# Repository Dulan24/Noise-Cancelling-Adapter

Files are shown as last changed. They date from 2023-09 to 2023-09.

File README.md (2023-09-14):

# Noise Cancelling Adapter

This project was targeting a cost-reduced noise-cancelling adapter which will cancel the ambient noise 
up to a certain level. Any headphone can be connected to the adapter and the adapter should be 
connected to the audio port of the device we are using. Then we have to switch on the adapter so that 
we can hear the music with noise reduced.  

Existing noise-cancelling headphones in the market are quite expensive. If a person has a normal 
headphone and he wants a noise-cancelling headphone, that person has to buy a separate 
headphone to it. It is a waste of money. Considering all these factors, I decided to design a noise-cancelling adapter to convert a normal headphone to a noise cancelling headphone. Since this is only 
an adapter it will be able to make this at lower cost. 

final product

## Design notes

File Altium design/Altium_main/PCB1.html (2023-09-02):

Altium customize

# Board Information Report

Date: | | 23-Jul-23
Time: | | 8:04:15 AM
Elapsed Time: | | 00:00:00
Filename: | | C:\Users\Dulan Lokugeegana\Desktop\Dulan_Mora\Acadamics\sem4\EN2160_electronic_design_realization\project\PCB\Altium_main\PCB1.PcbDoc
Units: | | mmmils

## Contents

Contents

Board Specification

General

## Board Specification

General
Board Size | 57mm x 66mm
Components on board | 36

Back to top

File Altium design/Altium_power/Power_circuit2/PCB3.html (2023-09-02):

Altium customize

# Board Information Report

Date: | | 23-Jul-23
Time: | | 8:03:48 AM
Elapsed Time: | | 00:00:00
Filename: | | C:\Users\Dulan Lokugeegana\Desktop\Dulan_Mora\Acadamics\sem4\EN2160_electronic_design_realization\project\PCB\Altium_power\Power_circuit2\PCB3.PcbDoc
Units: | | mmmils

## Contents

Contents

Board Specification

General

## Board Specification

General
Board Size | 57mm x 43mm
Components on board | 20

Back to top

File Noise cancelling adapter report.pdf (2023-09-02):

1 | P a g e

# University of Moratuwa

# Department of Electronics and Telecommunication

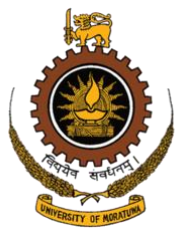
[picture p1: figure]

### EN2160 – Engineering Design Realization

### Report

### Noise Cancelling Adapter

200356A

2 | P a g e

## Table of Contents

3 | P a g e

4 | P a g e

List of figures

5 | P a g e

6 | P a g e

Acknowledgement

This report on Analog Noise Cancelling Adapter project, completed under the electronic part, is being submitted in great pleasure. In order to better grasp this section before learning any theories, we would like to express our profound gratitude to the following people.

My deepest gratitude is conveyed to the head of the department of Electronic and Telecommunication Dr. Ranga Rodrigo and all the senior and junior lecturers who guide us to do such a project. Specially, Dr. Jayathu who gave his views and more ideas in the mid evaluation and helped us in various ways to complete this project.

I would also want to express our gratitude to Prof. J.A.K.S. Jayasinghe for your valuable lectures that helped me accomplish this project in the manner of professional engineers. Analysis, production planning, final product packaging, design strategy, and other topics were all covered in our training. This gave us some insight into how to create the finished product.

Moreover, I convey my gratitude to all my batch mates who helped me immensely by working together and buying components together.

Dulan Lokugeegana,

Electronic and Telecommunication department,

University of Moratuwa,

Sri Lanka.

7 | P a g e

Abstract

The goal of this project is to buy a product which is readily available in the market and add a new feature which is not existing in that product. I decided to buy a normal headphone and add the new feature noise cancelling to it. The main marketing strategy is the cost saving. Normal headphone noise cancelling headphones are so much expensive. The cost of a normal headphone and the noise cancelling adapter is much less than the cost of noise cancelling headphone. In the first hand I thought of having the noise capturing microphones to be inside the adapter but, I found out that it should be near the ear. So, I had to add the mics with cables which should be attached to the headphone. All the calculations, component selection, PCB design and encloser design was done in such a way that the product is marketable.

8 | P a g e

Chapter 1 – Introduction

This project was targeting a cost reduced noise cancelling adapter which will cancel the ambient noise up to a certain level. Any headphone can be connected to the adapter and the adapter should be connected to the audio port of the device we are using. Then we have to switch on the adapter so that we can hear the music with noise reduced.

Problem identification

Existing noise cancelling headphones in the market are quite expensive. If a person has a normal headphone and he wants a noise cancelling headphone, that person has to buy an separate headphone to it. It is a waste of money. Considering all these things, it was decided to design a noise cancelling adapter to convert a normal headphone to a noise cancelling headphone. Since this is only an adapter it will be able to make this at lower cost.

Project objectives

Making a noise cancelling adapter at a lower cost. Moreover, there are other factors that should be consider like weight, size, shape, etc.… Most of the market available adapters are only able to be connected to laptops. Therefore, the product objectives are making a noise cancelling adapter which can be connected to any device, and it should be made at a lower cost with reduced size.

9 | P a g e

Project

The main concept used is capture the noise signal invert it and sum it with the music. Initially noise capturing mics was kept inside the adapter. Then a single mic can capture the noise. Music for the left and the right ears are separately inverted using unity gain inverting amplifier. Next music is added to noise by using a summing amplifier. Finally output the noiseless music for a 3.5mm jack.

First problem occurred is noise capturing. To capture the noise heard to ears the mic should be kept near the ear not in the adapter. Therefore, device needed 2 separate mics to capture the noise and they should be extending outwards. Two separate enclosers were made to insert mic modules which are needed to be connected to the headphone. Both mics are connected from two separate wires.

The second problem is power. Power to make the adapter working cannot be taking from a USB port as this should support any device (which might not have USB port). Therefore, separate replaceable 9V battry was used. Using buck convertor 9V is divided for +4.5V and -4.5V to power up the op amps which is used for amplifiers.

Since electrical signals are travelling at speed of light and sound is much slower comparatively. There should be a delay for negative noise before adding with the music. Therefore, an All Pass Filter is used to compensate it.

Delay calculation

Figure 1 delay calculation

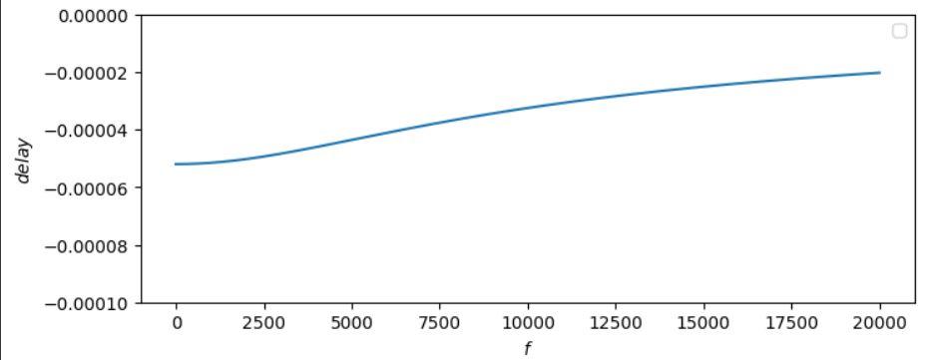
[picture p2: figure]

10 | P a g e

Figure 2 delay curve

Negative phase shift indicates movement to the right.

The mic is kept at about 1.4cm away from the ear.

Figure 3 distance time delay calculation

11 | P a g e

Block diagram

Figure 4 Basic Block Diagram

Basic Circuit Diagram

Figure 5 Basic Circuit Diagram

The above circuit modified and review from [1]

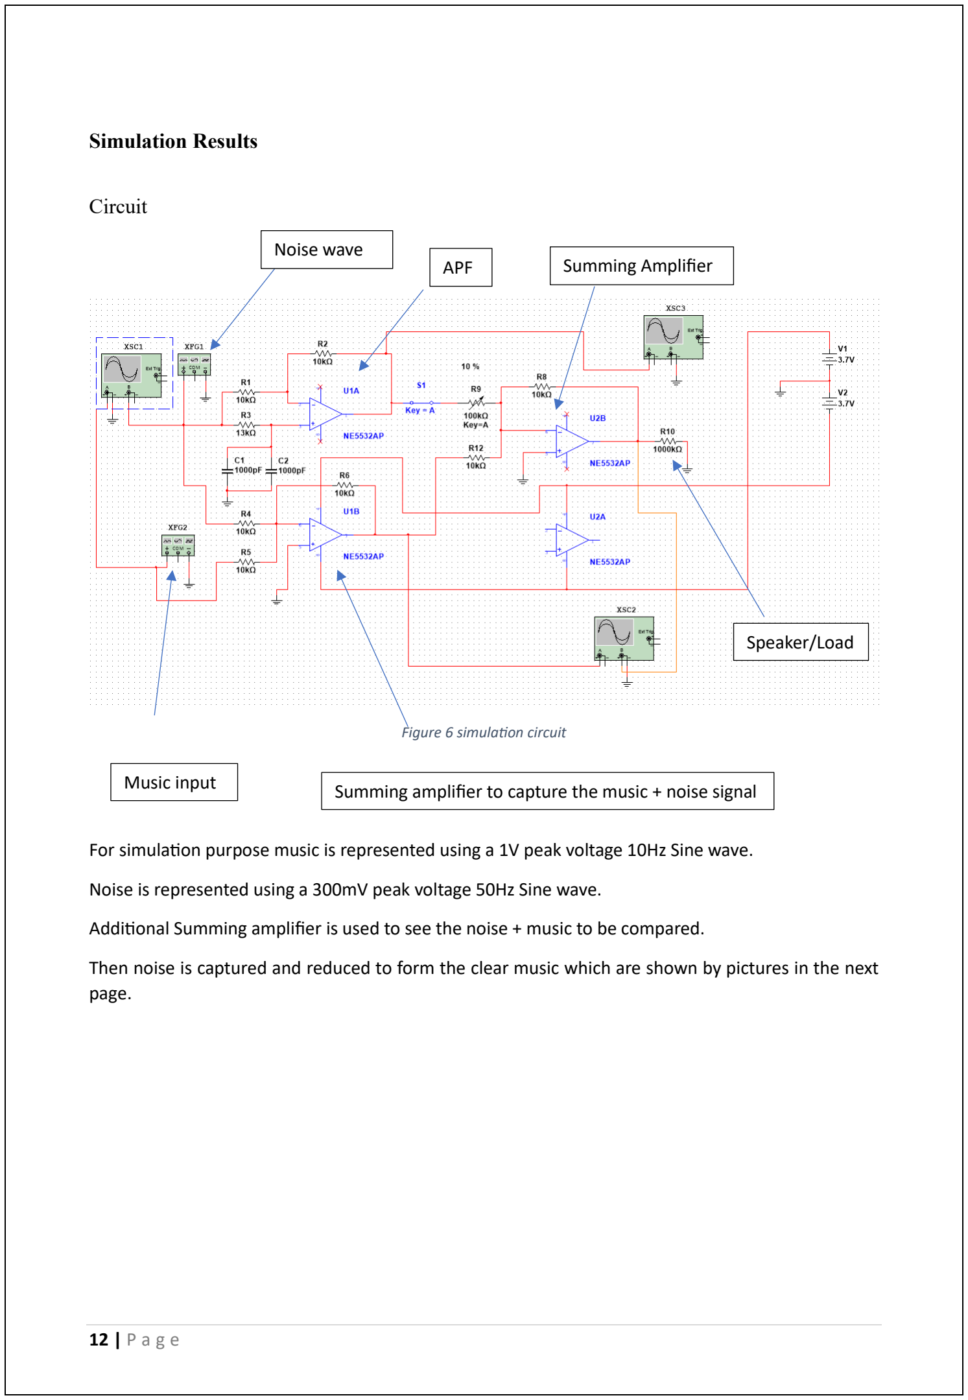
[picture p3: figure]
Simulation Results; Circuit; Figure 6 simulation circuit; page.; Noise wave; Music input; APF; Summing Amplifier; Speaker/Load

For simulation purpose music is represented using a 1V peak voltage 10Hz Sine wave.

Noise is represented using a 300mV peak voltage 50Hz Sine wave.

Additional Summing amplifier is used to see the noise + music to be compared.

Then noise is captured and reduced to form the clear music which are shown by pictures in the next

Summing amplifier to capture the music + noise signal

13 | P a g e

Figure 7 simulation result 1

Figure 8 simulation result 2

Noise signal | Music

Music with noise

Music noise free

14 | P a g e

Chapter 2 – conceptual report

Conceptual design was done with the group members to get more ideas and their opinion on designing the product.

Sketches Drawn by Group Members

Sketch 1
Drawn by Amarasinghe Y.E - 200029B

Figure 10 sketch 1

Figure 9 3D view 1

15 | P a g e

Sketch 2
Drawn by Vishagar A - 200686J

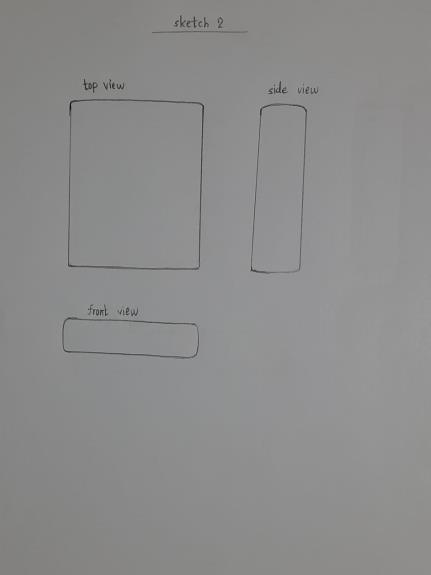
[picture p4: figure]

Figure 11 sketch 2

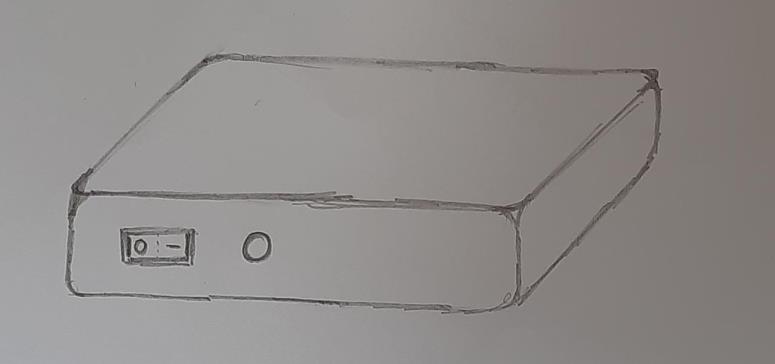
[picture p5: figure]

Figure 12 3D view 2

16 | P a g e

Sketch 3
Drawn by Liyanage P.H.S. – 200352H

Figure 13 sketch 3

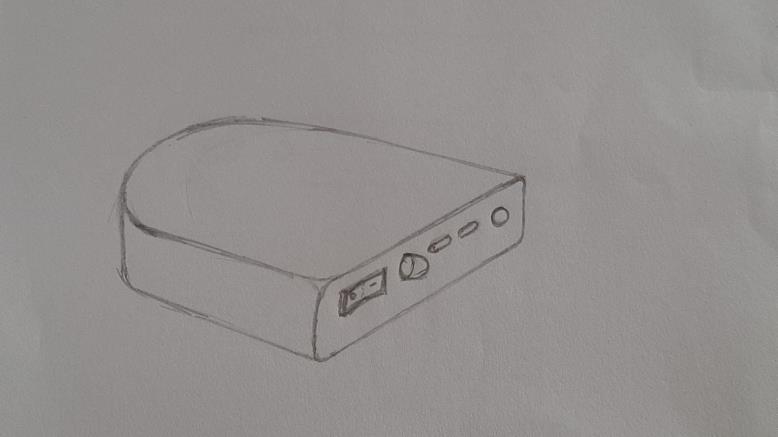
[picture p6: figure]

Figure 14 3D view 3

17 | P a g e

Summary of user feedback

1. The product is highly effective for users.
2. It should be little more affordable.
3. Minimum size.
4. Appearance and shape don’t matter much but, it should be smaller as possible.
5. Extra feature Bluetooth.

User Feedback sketches

Sketches are drawn such that it will be more

easy to use and with an attractive shape.

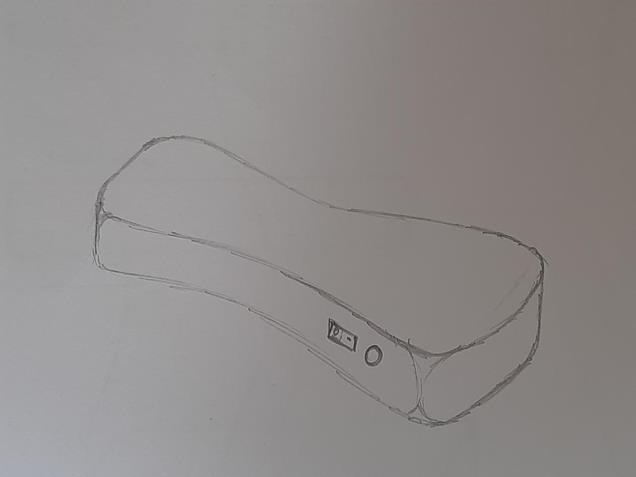
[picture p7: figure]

Figure 17 user feedback top view Figure 16 user feedback side view

Figure 15 user feedback 3D view

Figure 18 user feedback front view

18 | P a g e

Evaluation for Sketches

Graded form 1-5, where 5 is the best.

Criteria | Sketch 1 | Sketch 2 | Sketch 3 | User
User Interface | 4 | 4 | 4 | 5
Stability | 5 | 5 | 4 | 5
Durability | 4 | 5 | 4 | 5
Novelty | 5 | 3 | 5 | 5
User friendliness | 5 | 5 | 5 | 5
Mobility | 5 | 5 | 4 | 5
Reliability | 3 | 5 | 4 | 4
Cost | 3 | 4 | 4 | 4
Maintainance | 4 | 5 | 3 | 4
Simplicity | 2 | 5 | 4 | 5
Weight | 3 | 4 | 4 | 4
Attractiveness | 4 | 2 | 4 | 5
Total | 47 | 52 | 49 | 56

19 | P a g e

Block Diagram

Block 1

Figure 19 block diagram 1

Block 2

Figure 20 block diagram 2

20 | P a g e

Block 3

Figure 21 block diagram 3

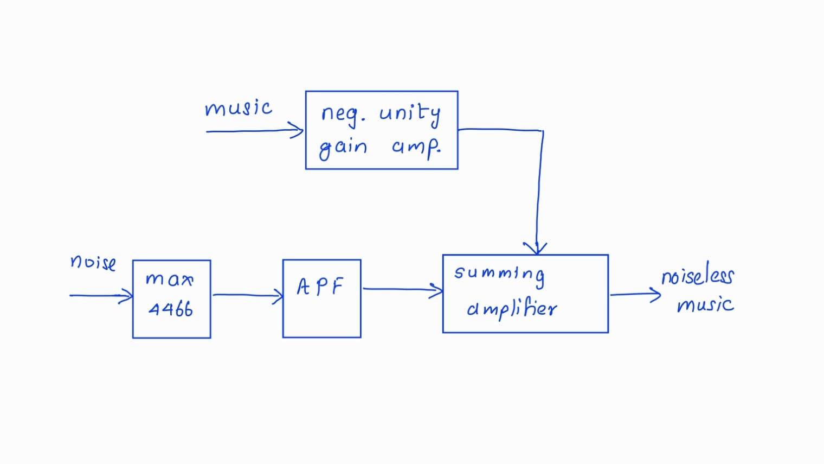
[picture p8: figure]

21 | P a g e

User Feedback Block Diagram

Block diagram is same as this is the only circuit for analog noise cancelling. Therefore, this is chosen.

Figure 22 user feedback block diagram

The above block diagram is selected for the Preliminary Design.

Bluetooth addition feature is discarded as this will be an analogue circuit.

22 | P a g e

Evaluation for block diagram

Graded form 1-5, where 5 is the best

Criteria | User Block Diagram | Block Diagram 1 | Block Diagram 2 | Block Diagram 3
Simplicity | 5 | 3 | 3 | 4
Accuracy | 2 | 4 | 3 | 2
User friendly | 3 | 3 | 3 | 3
Updatability | 4 | 1 | 3 | 4
Troubleshooting | 5 | 2 | 2 | 5
Feasibility | 5 | 3 | 1 | 5
Durability | 5 | 3 | 3 | 5
Total | 29 | 19 | 18 | 28

23 | P a g e

Selected Sketches

Figure 25 selected sketch top view | Figure 24 selected sketch side view

Figure 23 selected sketch front view

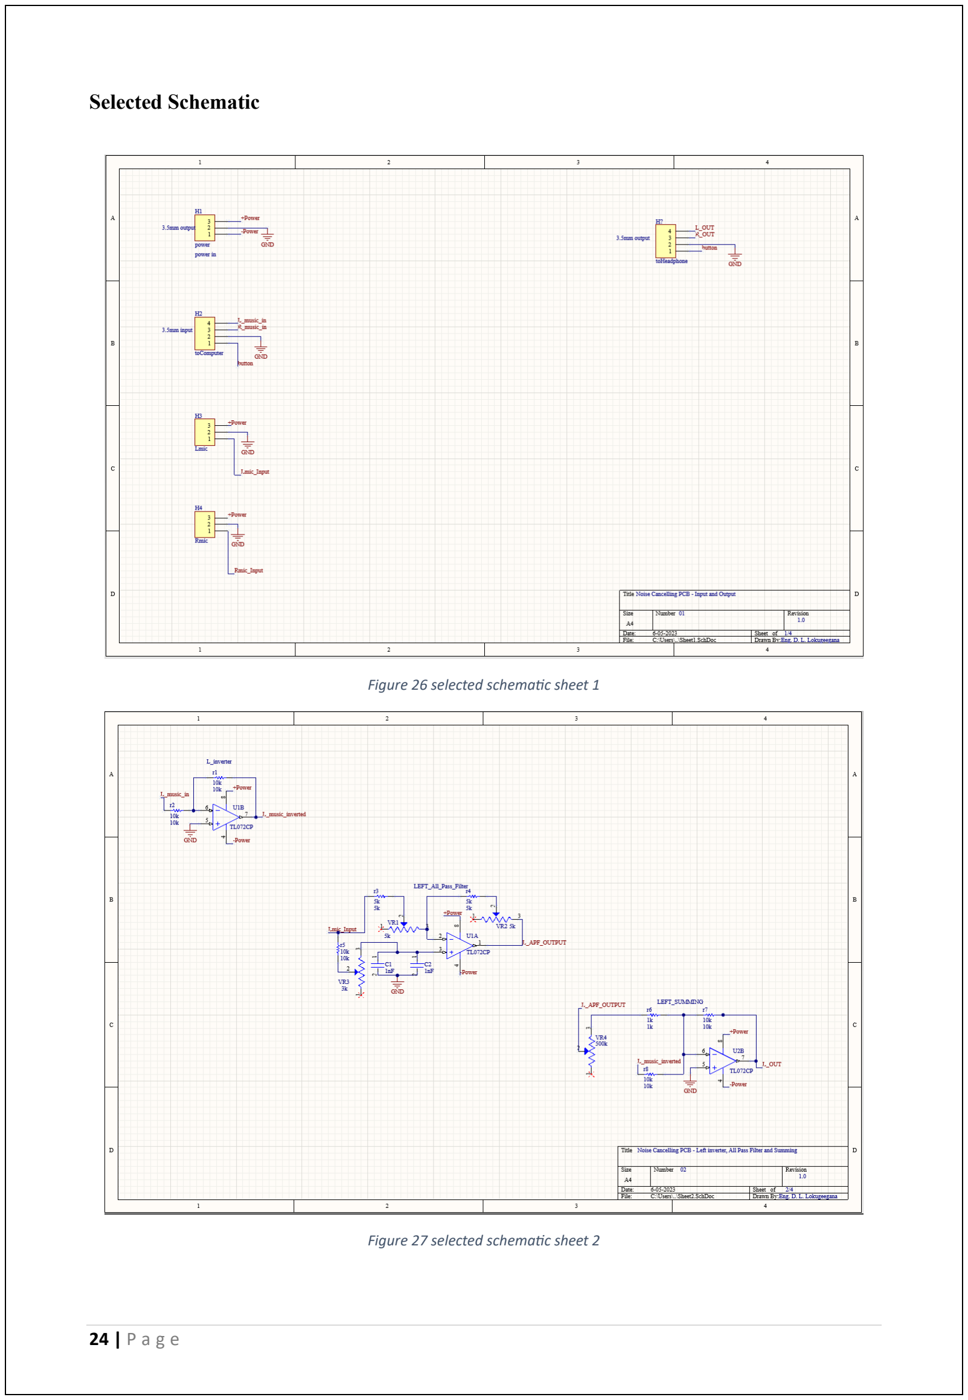
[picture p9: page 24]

24 | P a g e

Selected Schematic

Figure 26 selected schematic sheet 1

Figure 27 selected schematic sheet 2

25 | P a g e

Figure 28 selected schematic sheet 3

Figure 29 selected schematic sheet 4

26 | P a g e

Chapter 3 – preliminary report

Schematic and Solidworks

Power circuit Schematic

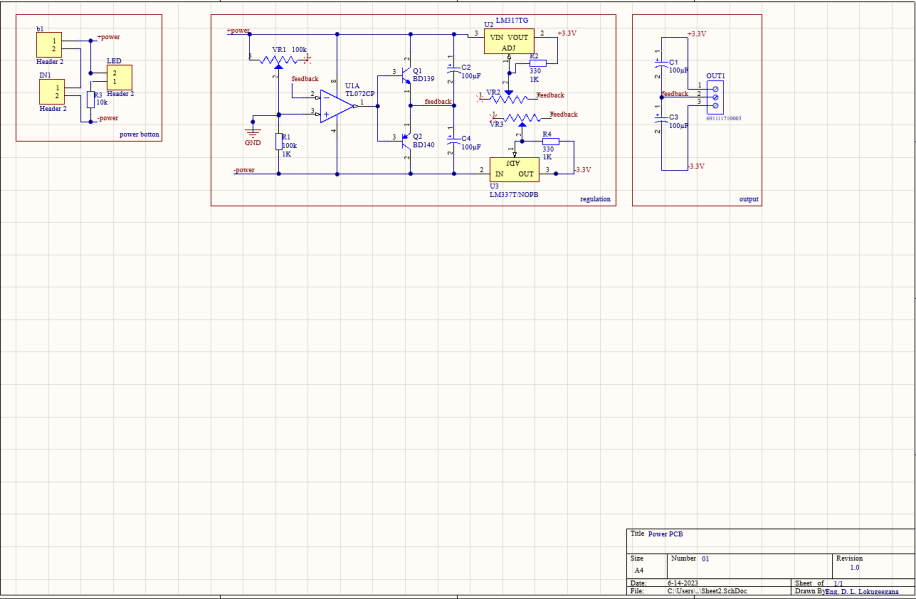
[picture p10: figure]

Figure 30 power circuit schematic

Main PCB Schematic

Figure 31 main circuit schematic

27 | P a g e

Implemented SolidWorks

Lower Part

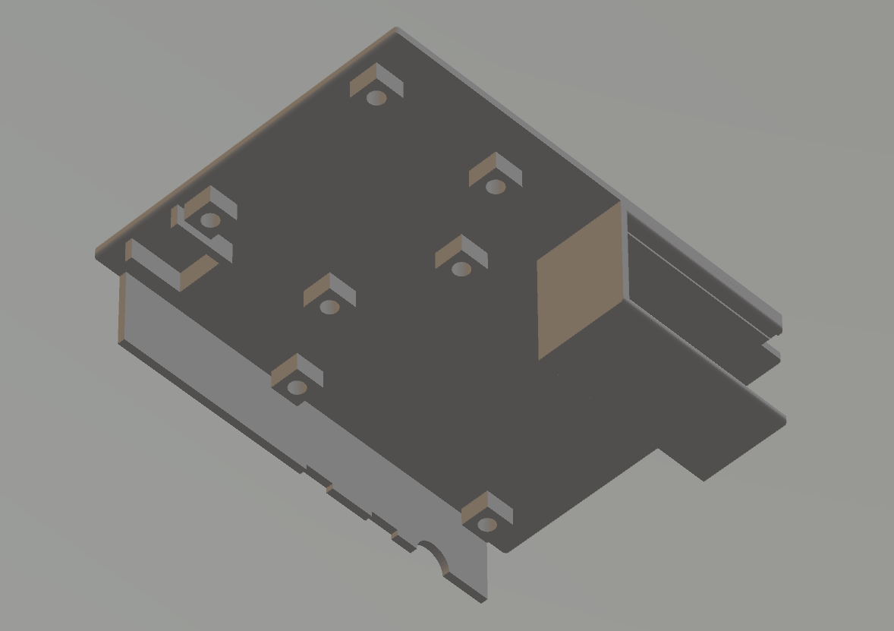
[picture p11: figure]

Figure 32 printed encloser lower part

Upper Part

Figure 33 printed encloser upper part

28 | P a g e

Ear part

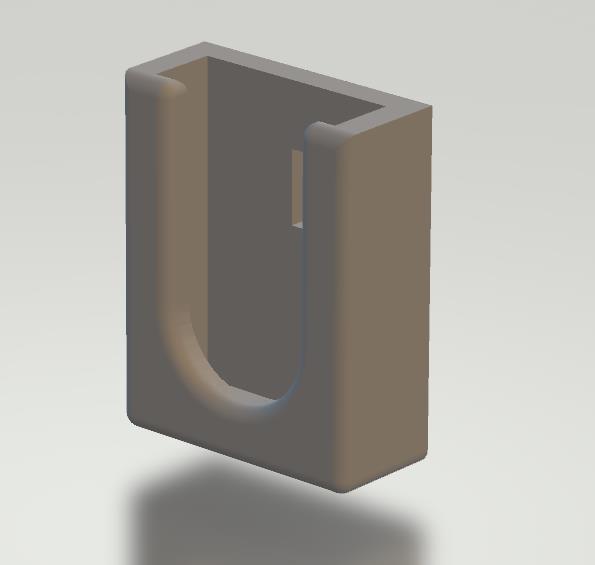
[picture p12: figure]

Figure 34 printed encloser ear part

Battery lid

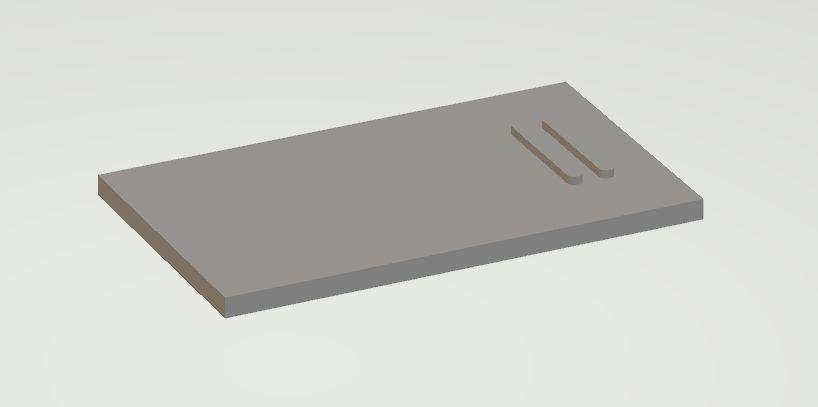
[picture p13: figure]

Figure 35 printed encloser battery lid

29 | P a g e

Problems Identified

1. Schematic is not done in professional manner.
a. Status box filling.
b. Naming components from top to bottom for eazy identification.
c. Minimizing usage of wires (instead use net labels).
2. Encloser moldability
a. Draft angle analysis.
b. Design in a way which can be moldable.
c. Injection molding process.
3. Appearance for marketing
a. Importance of final appearance for marketing.
b. Attractiveness by colour and texture.
4. User need analysis
a. Take user feedback for better product implementation.
b. User feedback analysis methods.
5. Design cycle implementation
a. How to do proper design.
b. How the product gets improved by design cycles.
6. Product manual and documentation
a. User manual.
b. Maintenance manual.
c. How to keep proper and complete documentation.

30 | P a g e

Problems and Improvements Provided by Group Members

Problems Identified
1. Size ( how to make small as possible )
2. External wire minimization.
3. Analog circuit accuracy.

Improvements
1. Using Mics in the device to capture noise.
2. Digital noise cancelling circuit.

31 | P a g e

Problems and Improvements Provided by Users

Problems Identified
1. Size ( how to make small as possible )
2. Attractiveness.
3. External wire minimization

Improvements
1. Using Mics in the device to capture noise.
2. Make it more user-friendly shape.

32 | P a g e

Chapter 4 – detailed design

Block diagram

Figure 36 detailed design basic block diagram

33 | P a g e

Circuit

Figure 37 detailed design circuit

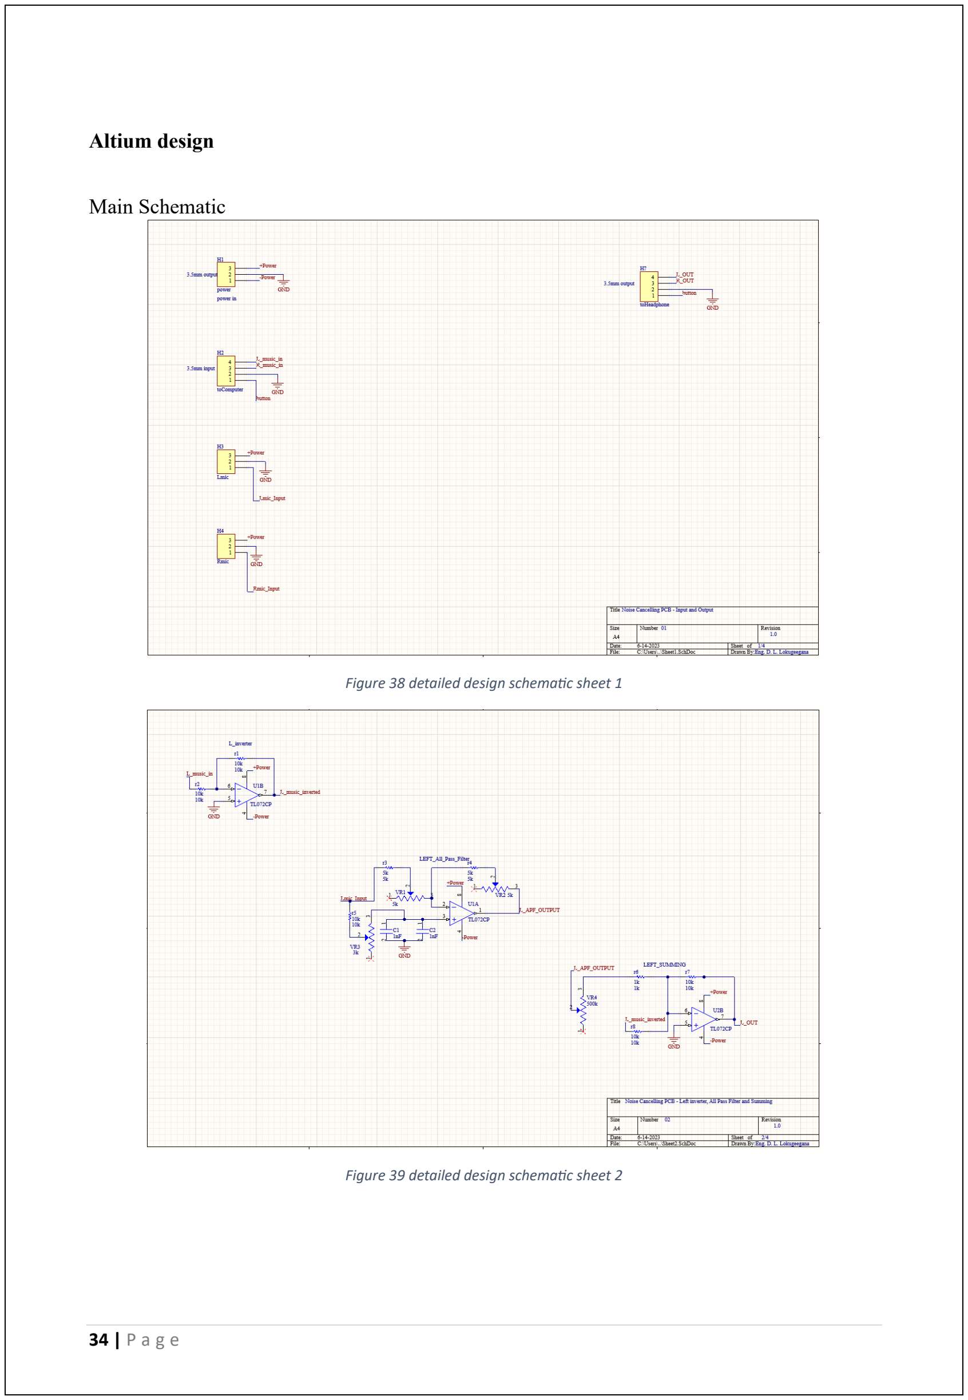
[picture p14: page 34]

34 | P a g e

Altium design

Main Schematic

Figure 38 detailed design schematic sheet 1

Figure 39 detailed design schematic sheet 2

35 | P a g e

Figure 40 detailed design schematic sheet 3

Figure 41 detailed design schematic sheet 4

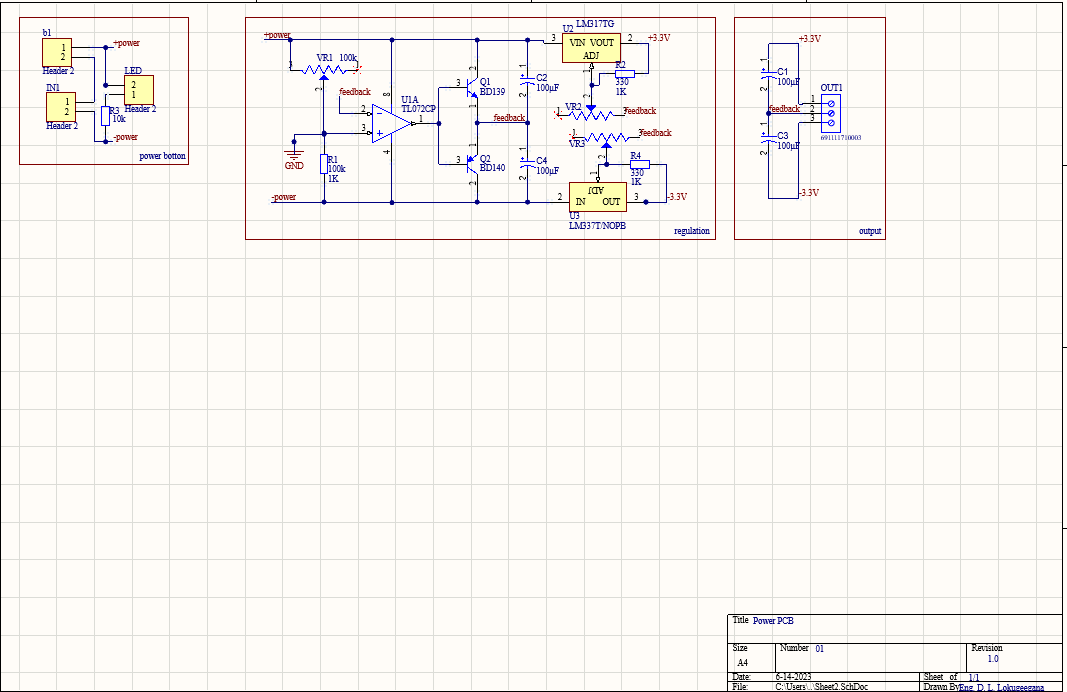
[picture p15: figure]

36 | P a g e

Figure 42 detailed design power circuit schematic sheet

37 | P a g e

PCB

Figure 43 main PCB altium

Figure 44 power PCB altium

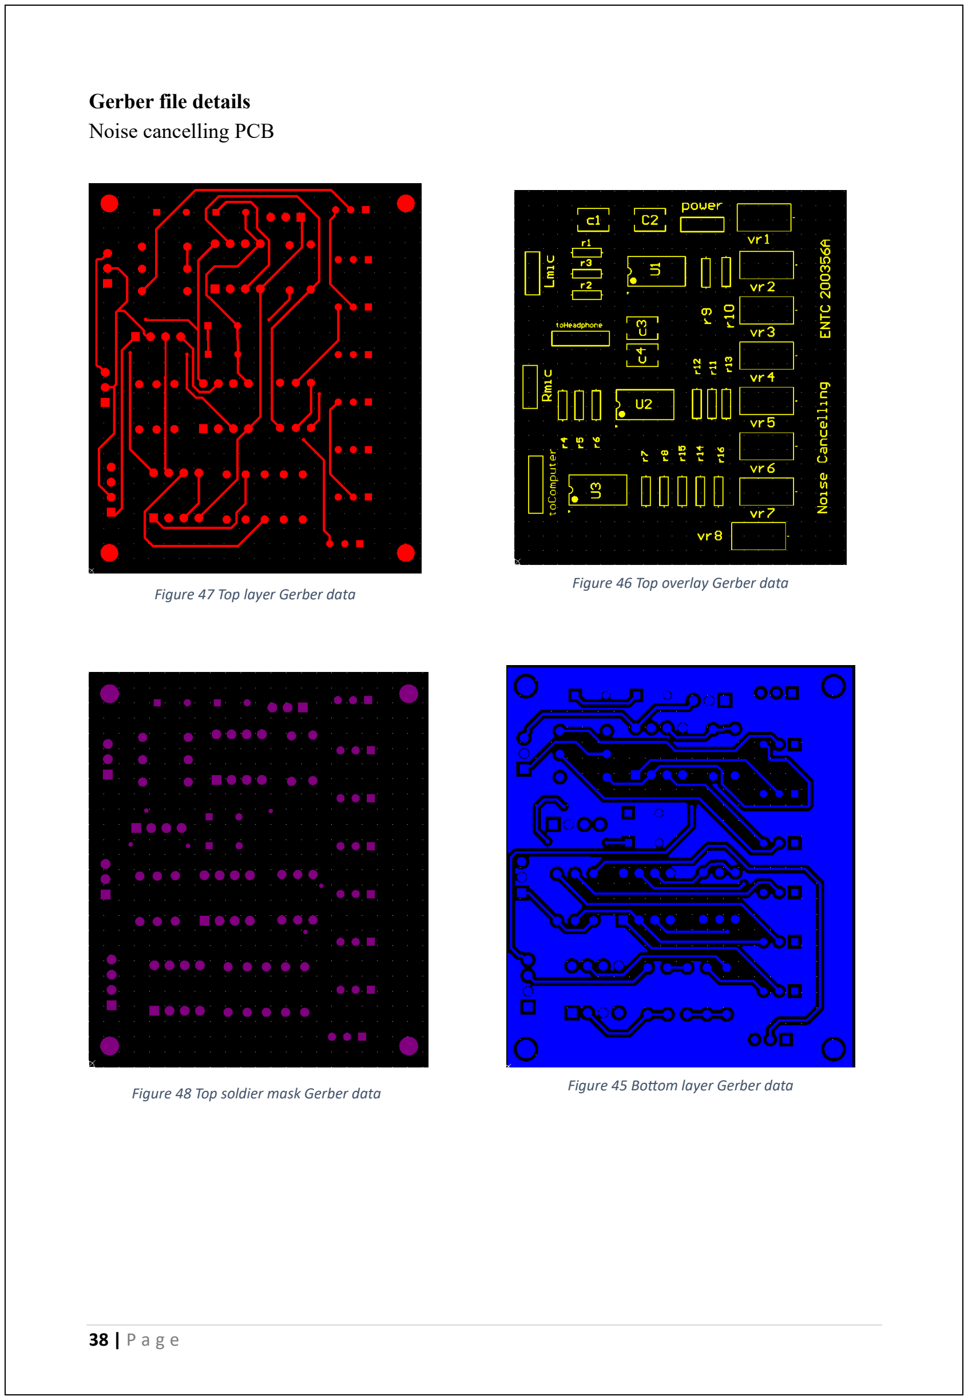
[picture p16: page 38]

38 | P a g e

Gerber file details
Noise cancelling PCB

Figure 48 Top soldier mask Gerber data

Figure 47 Top layer Gerber data

Figure 46 Top overlay Gerber data

Figure 45 Bottom layer Gerber data

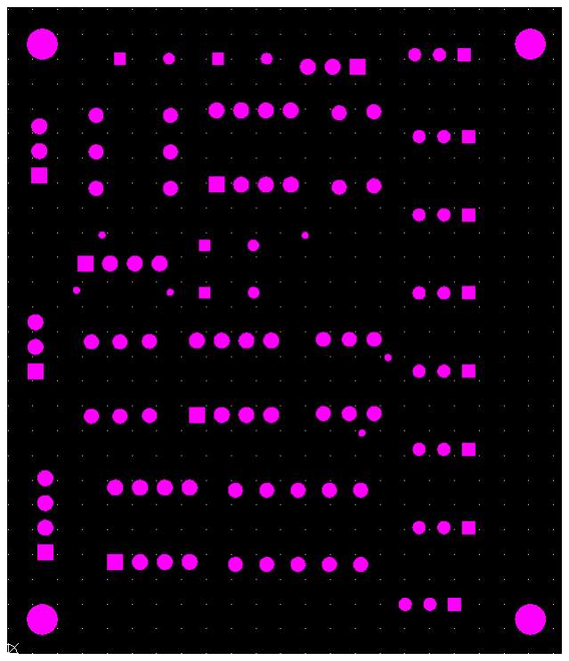
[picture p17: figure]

39 | P a g e
Figure 50 Bottom soldier mask Gerber data | Figure 49 Drill drawing layer pair Gerber data

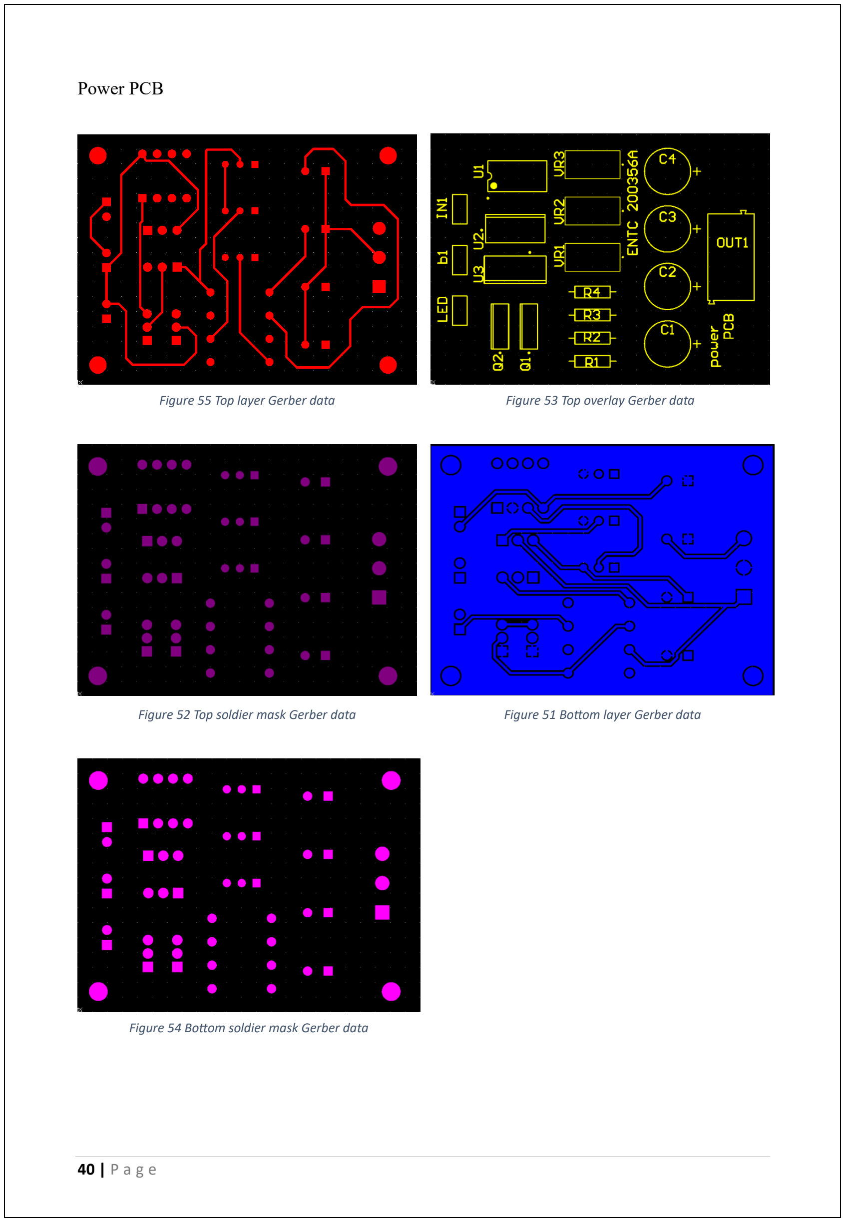
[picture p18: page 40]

40 | P a g e

Power PCB

Figure 55 Top layer Gerber data | Figure 53 Top overlay Gerber data
Figure 52 Top soldier mask Gerber data | Figure 51 Bottom layer Gerber data

Figure 54 Bottom soldier mask Gerber data

41 | P a g e

Images of PCB after soldering and after first testing

Figure 57 power PCB after soldering | Figure 56 Noise cancelling PCB after soldering

Figure 58 implementation

42 | P a g e

Encloser

Enclosers are going to be made using injection molding for mass scale and it is 3D printed for the prototype.

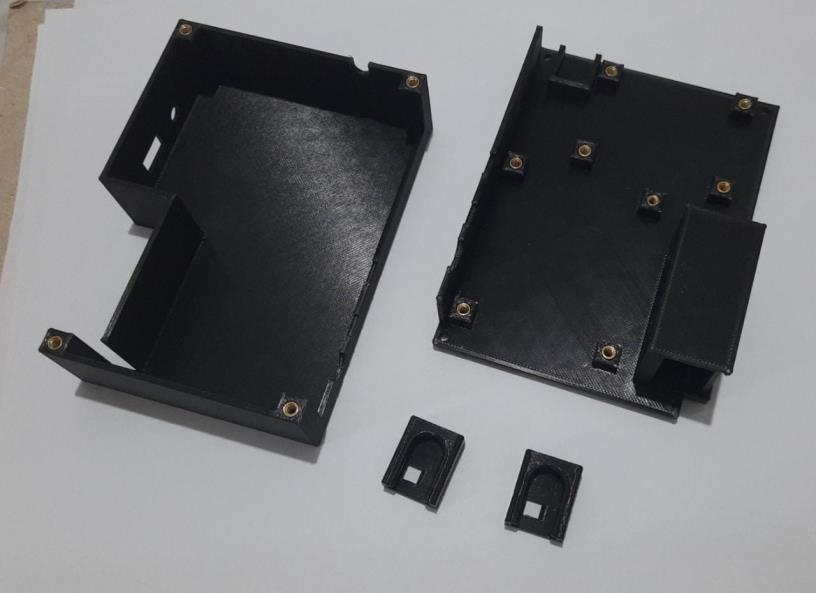
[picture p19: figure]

Figure 59 encloser uncombined

Figure 60 encloser combined

43 | P a g e

Chapter 5 – Manufacturing

PCB fabrication process

There are 2 main PCBs both are 2-layer PCB. Power PCB is converting 9V input to +3.3V and -3.3V outputs.

Both PCB fabrication process is outsourced to reduce cost

and get high quality.

PCB Manufacturer: Jia Li Chuang (Hong Kong) Co., Limited (JLC PCB)

Noice cancelling PCB

Base material – FR-4

Dimensions - 57mm x 66mm

Power PCB

Base material – FR -4

Dimentions – 57mm x 43mm

Figure 62 power PCB

Figure 61 Noice cancelling PCB

44 | P a g e

BOM

No | Manufacture part no | Description Quantity | Price | Supplier
1 https://www.smart- | prototyping.com/MAX4466-Electret-Microphone-Amplifier-Module (https://www.smart-prototyping.com/MAX4466-Electret-Microphone-Amplifier-Module) | Max 4466 sensor | 2 | 830 | Smart prototypi ng
2 https://tronic.lk/product/telephone-cable-4- | wire-per-meter (https://tronic.lk/product/telephone-cable-4-wire-per-meter) | Telephone cables | 1m | 80 | Local supplier
3 https://tronic.lk/product/5-pin-headphone- | jack-pcb-mount-female-3-5mm-stereo (https://tronic.lk/product/5-pin-headphone-jack-pcb-mount-female-3-5mm-stereo) | 3.5mm audio jack | 1 | 90 | Local supplier
4 | | 4pin JST | 1 | 60 | Local supplier
5 | | 3pin JST | 1 | 90 | Local supplier
6 | | 2pin JST | 2 | 40 | Local supplier
7 3.5mm | | audio cable | 1 | 350 | Local supplier
8 | | LED | 1 | 10 | Local supplier
9 Power | | button | 1 | 40 | Local supplier
10 9V battery | | connector | 1 | 80 | Local supplier
11 | | 100uF cap | 4 | 20 | Local supplier
12 3way | | connector | 1 | 40 | Local supplier
13 | | 330Ω | 2 | 10 | Local supplier
14 | | 10kΩ | 9 | 45 | Local supplier
15 | | 100kΩ | 1 | 5 | Local supplier
16 https://www.mouser.com/ProductDetail/Texas- | Instruments/TL072CP?qs=5nGYs9Do7G3e6Tx9u HIgUA%3D%3D (https://www.mouser.com/ProductDetail/Texas-Instruments/TL072CP?qs=5nGYs9Do7G3e6Tx9uHIgUA%3D%3D) | TL072cp | 4 | 1350 | Mouser electroni cs.
17 | https://www.mouser.com/c/?q=BD139 | BD139 | 1 | 220 | Mouser electroni cs.
18 | https://www.mouser.com/c/?q=bd140 | BD140 | 1 | 245 | Mouser electroni cs.

45 | P a g e
19 https://www.mouser.com/ProductDetail/Texas- | Instruments/LM317KCS?qs=Zu35EjizYSTLhqY3l Vz7nA%3D%3D (https://www.mouser.com/ProductDetail/Texas-Instruments/LM317KCS?qs=Zu35EjizYSTLhqY3lVz7nA%3D%3D) | LM317 | 1 | 290 | Mouser electroni cs.
20 https://www.mouser.com/ProductDetail/TexasI | nstruments/ LM337KCSE3?qs=iSMark9AYDWpc5pQ5gDgRw %3D%3D (https://www.mouser.com/ProductDetail/TexasInstruments/LM337KCSE3?qs=iSMark9AYDWpc5pQ5gDgRw%3D%3D) | LM337 | 1 | 350 | Mouser electroni cs.
21 10kΩ var. | | resistor | 8 | 320 | Local supplier
22 100kΩ var. | | resistor | 1 | 40 | Local supplier
23 500kΩ var. | | resistor | 2 | 80 | Local supplier
24 | | 1kΩ | 2 | 10 | Local supplier
25 | | 3.3kΩ | 6 | 30 | Local supplier
26 | | 1nF | 4 | 20 | Local supplier
| Total cost of material | | | 7445

Mass production encloser cost – 200

Soldiering cost – 200

Total cost – Rs 7845

Estimated selling price is 10000

46 | P a g e

Chapter 6 – results and conclusion

Noise cancelling is only to a certain level. Problem is with the noise capturing mics. These mics are not sensitive enough to capture all the noise heard.

Product can be made in mass scale if encloser is molded instead of 3D print.

Product encloser is to be changed to be more attracted while PCBs can be reduced in size by using surface mounting components in mass production.

Figure 63 final product

47 | P a g e

Chapter 7 - User manual

Initializing

1. There are two gray colour wires which contains the microphone user have to fix them to the headphone as in the below image.

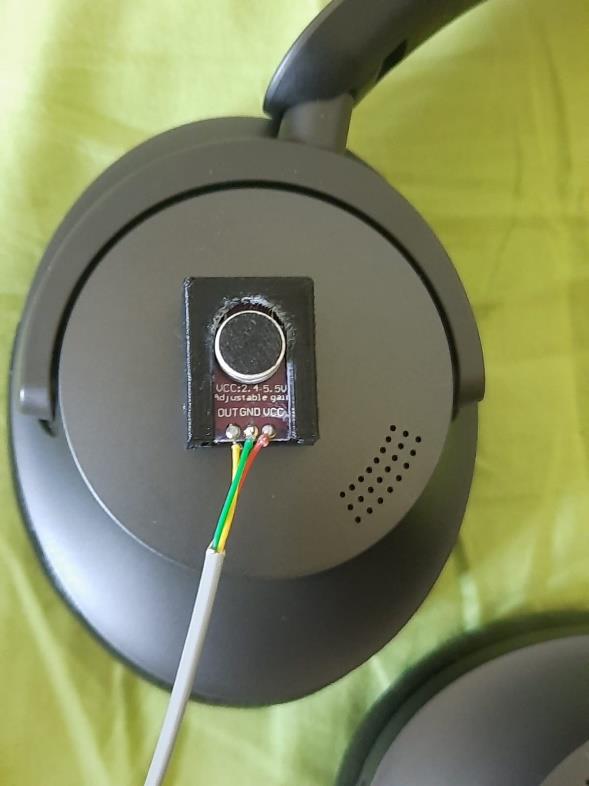
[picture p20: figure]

Figure 64 mic attach

2. There is a printed attachment tape on the mic so that the user can identify which mic should be attached to which sided of the headphone. This is a very important step.

R is to the right

L is to the left

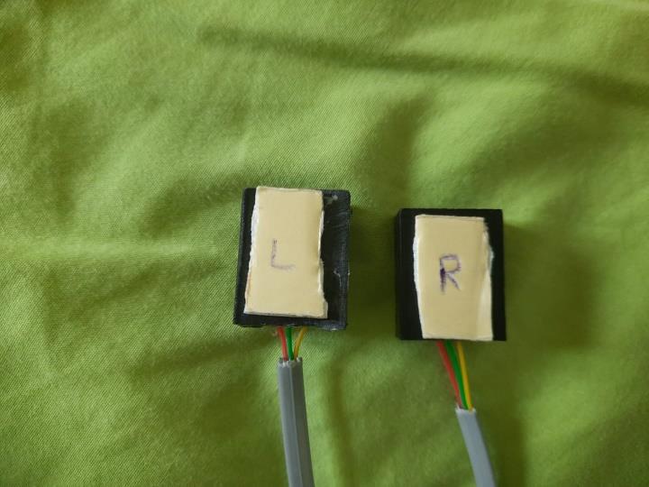
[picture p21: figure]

Figure 65 mic attachment side identify

48 | P a g e

Using

1. After doing the initializing steps user can plug the 3.5mm wire to the device.

Figure 66 plug adapter to device

2. Then user can plug the headphone 3.5mm jack to the 3.5mm port in the adapter.

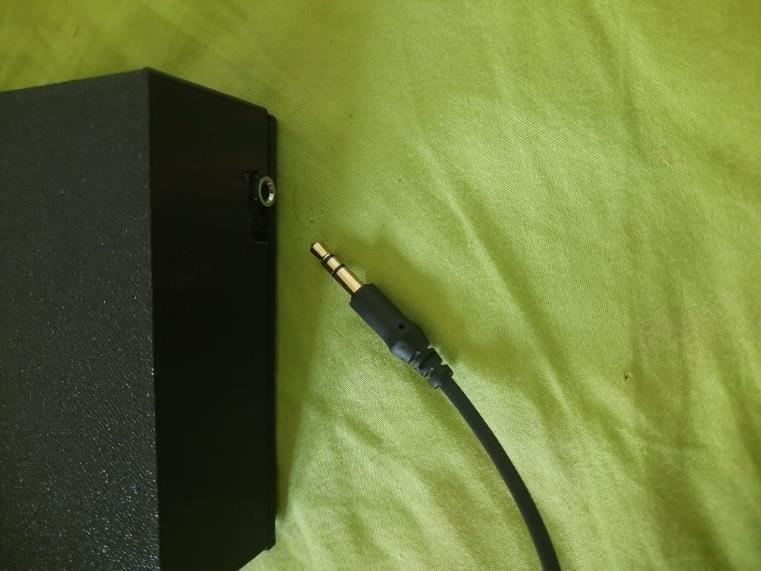
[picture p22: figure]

Figure 67 plug headphone to adapter

49 | P a g e
3. The listen to the music by switching on the device which will be indicated by a red LED.

Figure 69 before switching on

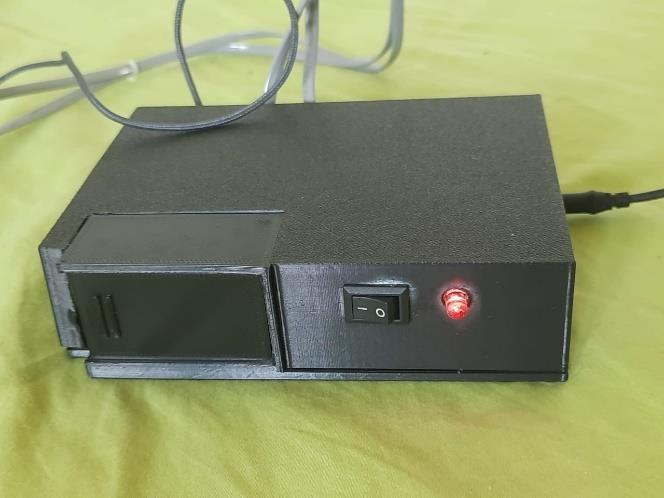
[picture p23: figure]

Figure 68 after switching on

50 | P a g e

Battery changing

Battery lid needs to be slide to the left as shown in the figure.

Figure 70 battery lid slide direction

Them change the 9V battery and closed the lid again.

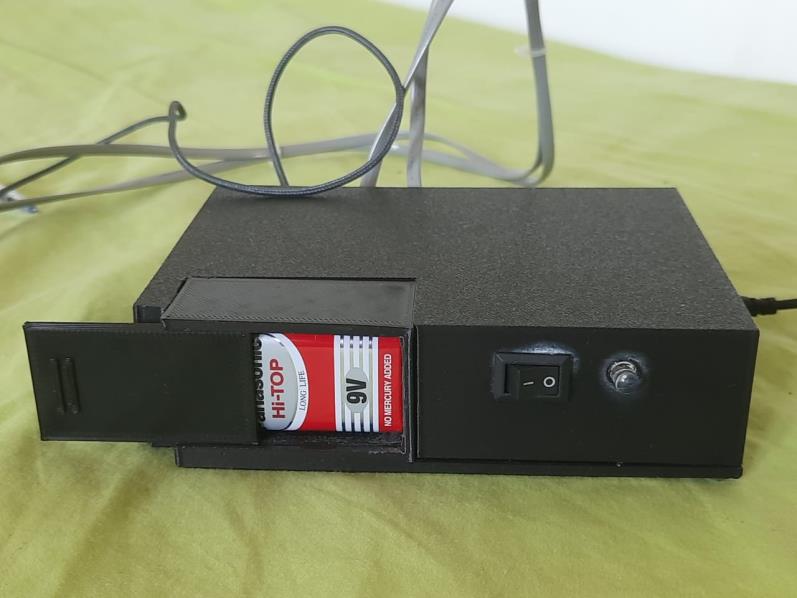
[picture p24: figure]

Figure 71 battery lid open

51 | P a g e

Bibliography

[1] Sbacilico, "Analog Noise cancelling Headphone," AUTODESK Instructables, [Online]. Available: https://www.instructables.com/Analog-Noise-Cancelling-Headphones/. [Accessed 11 03 2023].

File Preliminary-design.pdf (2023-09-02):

## University of Moratuwa

## Department of Electronics and Telecommunication


### EN2160 – Engineering Design Realization

### Report – Preliminary Design

### Noise Cancelling Adapter

200356A

Contents


Schematic and Solidworks

Power circuit Schematic

Main PCB Schematic

Implemented SolidWorks

Lower Part

Upper Part


Ear part

Battery lid


Problems Identified

1. Schematic is not done in professional manner.
a. Status box filling.
b. Naming components from top to bottom for eazy identification.
c. Minimizing usage of wires (instead use net labels).
2. Encloser moldability
a. Draft angle analysis.
b. Design in a way which can be moldable.
c. Injection molding process.
3. Appearance for marketing
a. Importance of final appearance for marketing.
b. Attractiveness by colour and texture.
4. User need analysis
a. Take user feedback for better product implementation.
b. User feedback analysis methods.
5. Design cycle implementation
a. How to do proper design.
b. How the product gets improved by design cycles.
6. Product manual and documentation
a. User manual.
b. Maintenance manual.
c. How to keep proper and complete documentation.

Problems and Improvements Provided by Group Members

Problems Identified
1. Size ( how to make small as possible )
2. External wire minimization.
3. Analog circuit accuracy.

Improvements
1. Using Mics in the device to capture noise.
2. Digital noise cancelling circuit.

Problems and Improvements Provided by Users

Problems Identified
1. Size ( how to make small as possible )
2. Attractiveness.
3. External wire minimization

Improvements
1. Using Mics in the device to capture noise.
2. Make it more user friendly shape.


Schematic and Solidworks of Improved Design

Schematic

Main Schematic




SolidWorks




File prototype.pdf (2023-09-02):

## University of Moratuwa


### Department of Electronics and Telecommunication

### EN2160 – Engineering Design Realization

200356A

Lokugeegana D.L.


1. Images of PCB after soldering and after first testing
Figure 1 Power PCB | Figure 2 Main PCB

Figure 3 Implementation

Images of the Encloser


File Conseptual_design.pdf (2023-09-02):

## University of Moratuwa

## Department of Electronics and Telecommunications


### EN2160 – Engineering Design Realization

### Conceptual Design

200356A

## Table of Contents

## Sketches Drawn by Group Members

### Sketch 1

Drawn by Amarasinghe Y.E - 200029B


Block diagram is same as this is the only circuit for analog noise cancelling.

### Sketch 2

Drawn by Vishagar A - 200686J


Block diagram is same as this is the only circuit for analog noise cancelling.

### Sketch 3

Drawn by Liyanage P.H.S. – 200352H


Block diagram is same as this is the only circuit for analog noise cancelling.

## Summary of user feedback

1. The product is highly effective for users.
2. It should be little more affordable.
3. Minimum size.
4. Appearance and shape don’t matter much but, it should be smaller as possible.
5. Extra feature Bluetooth.

## User Feedback sketches


Sketches are drawn such that it will be more

easy to use and with an attractive shape.


## Evaluation for Sketches

Graded form 1-5, where 5 is the best.

Criteria | Sketch 1 | Sketch 2 | Sketch 3 | User
User Interface | 4 | 4 | 4 | 5
Stability | 5 | 5 | 4 | 5
Durability | 4 | 5 | 4 | 5
Novelty | 5 | 3 | 5 | 5
User friendliness | 5 | 5 | 5 | 5
Mobility | 5 | 5 | 4 | 5
Reliability | 3 | 5 | 4 | 4
Cost | 3 | 4 | 4 | 4
Maintainance | 4 | 5 | 3 | 4
Simplicity | 2 | 5 | 4 | 5
Weight | 3 | 4 | 4 | 4
Attractiveness | 4 | 2 | 4 | 5
Total | 47 | 52 | 49 | 56

## Block Diagram

### Block 1


### Block 2


### Block 3


## User Feedback Block Diagram

Block diagram is same as this is the only circuit for analog noise cancelling. Therefore this is chosen.


The above block diagram is selected for the Preliminary Design.

Bluetooth addition feature is discarded as this will be an analogue circuit.

## Evaluation for block diagram

Graded form 1-5, where 5 is the best

Criteria | User Block Diagram | Block Diagram 1 | Block Diagram 2 | Block Diagram 3
Simplicity | 5 | 3 | 3 | 4
Accuracy | 2 | 4 | 3 | 2
User friendly | 3 | 3 | 3 | 3
Updatability | 4 | 1 | 3 | 4
Troubleshooting | 5 | 2 | 2 | 5
Feasibility | 5 | 3 | 1 | 5
Durability | 5 | 3 | 3 | 5
Total | 29 | 19 | 18 | 28

## Selected Sketches


## Selected Schematic


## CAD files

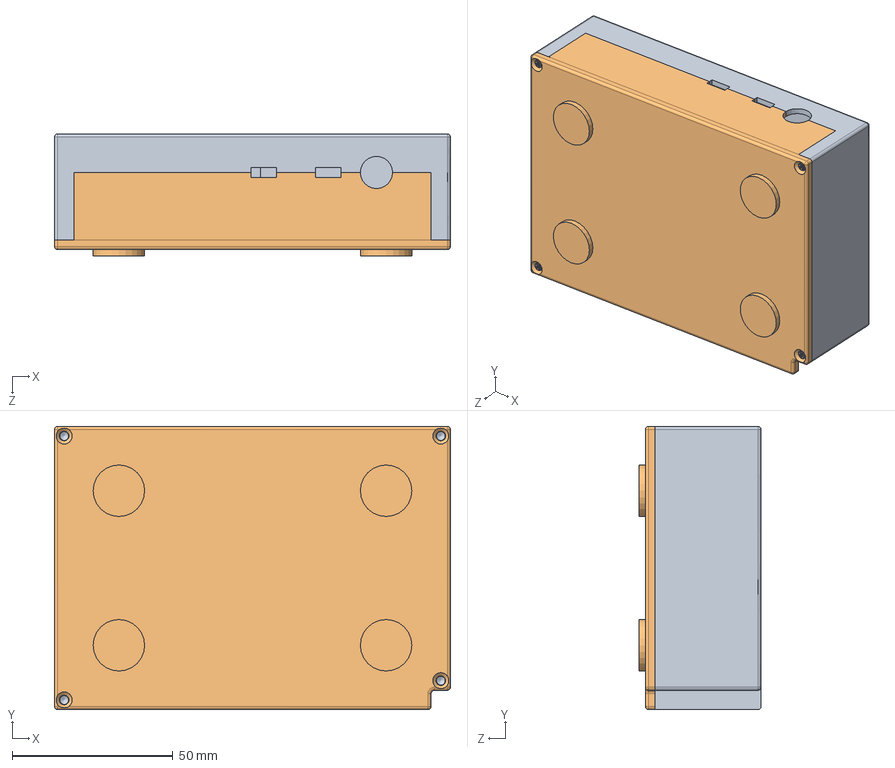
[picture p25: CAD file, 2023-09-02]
SolidWorks Design/Assemtopandbottom.SLDASM
123.0 x 88.0 x 38.0 mm
bottompart
toppart

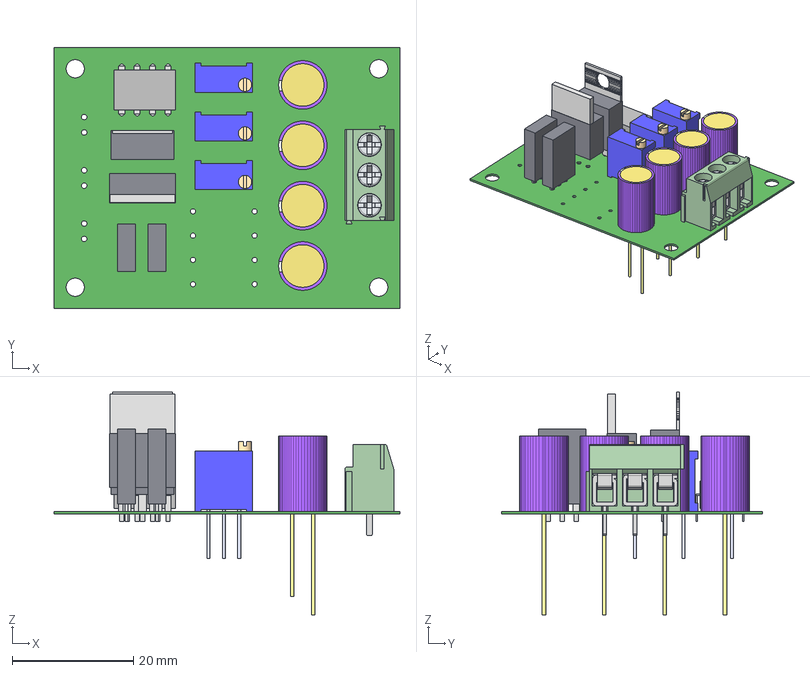
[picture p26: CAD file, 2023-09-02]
SolidWorks Design/PCB3.step
57.0 x 43.0 x 36.7 mm
Extruded x 90
6911117100xx_CAGE x 3
6911117100xx_PIN x 3
6911117100xx_VIS+ x 3

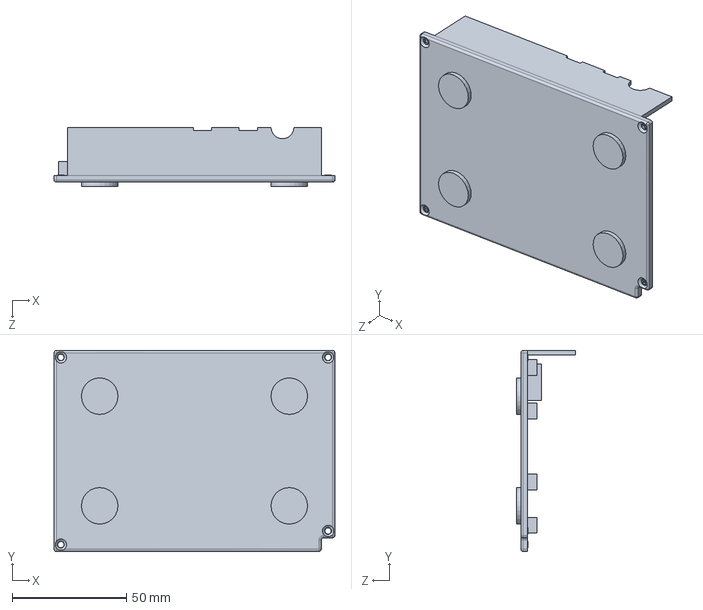
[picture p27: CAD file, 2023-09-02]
SolidWorks Design/bottompart.SLDPRT
123.0 x 88.0 x 26.0 mm

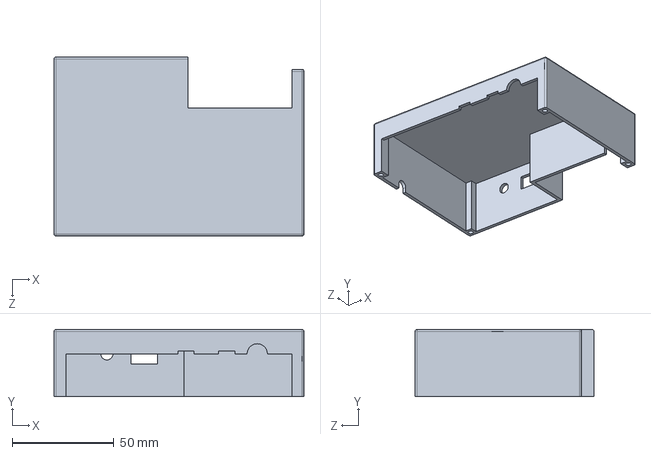
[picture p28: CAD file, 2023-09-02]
SolidWorks Design/toppart.SLDPRT
123.0 x 33.0 x 88.0 mm

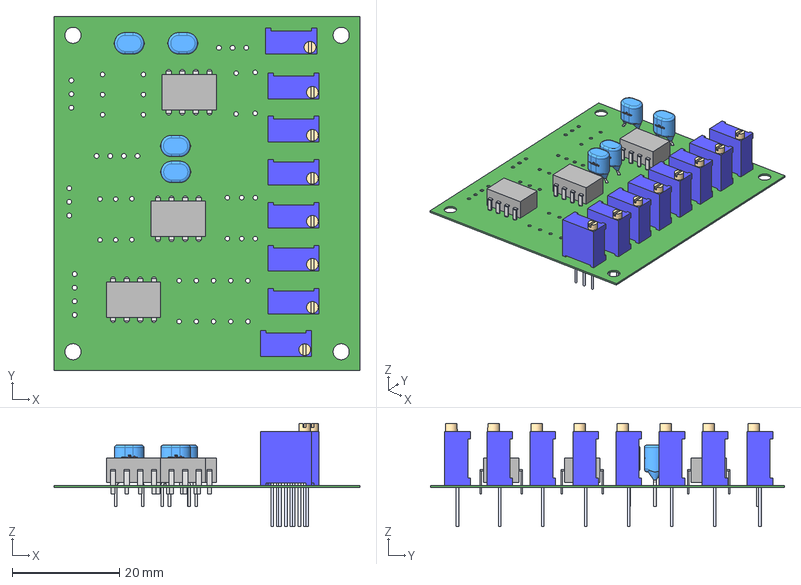
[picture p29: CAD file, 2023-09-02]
SolidWorks Design/PCB1.step
57.0 x 66.0 x 19.3 mm
Leads x 4
Logo x 4
Extruded x 75

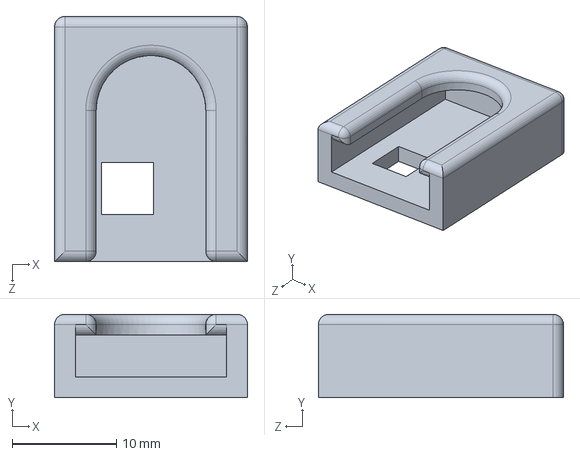
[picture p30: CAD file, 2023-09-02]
SolidWorks Design/earpart.SLDPRT
18.5 x 8.00 x 23.5 mm

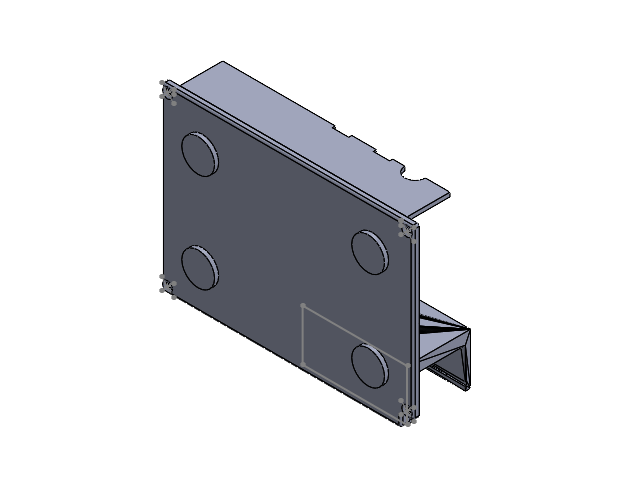
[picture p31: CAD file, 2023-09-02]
SolidWorks Design/Assemlowerand batterycover.SLDASM
bottompart
ORC-KIT_9V_Battery_Holder

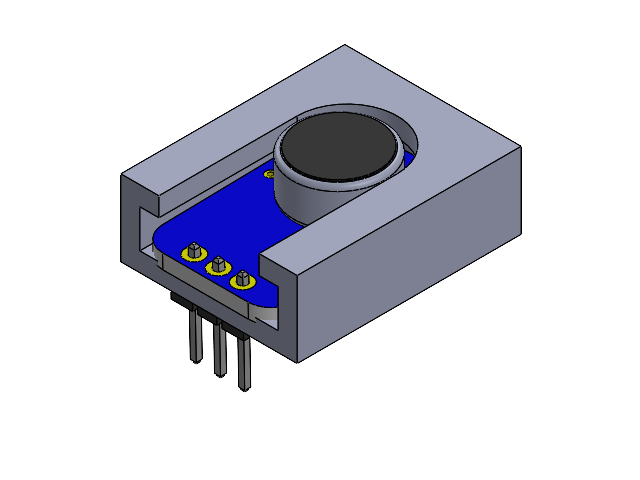
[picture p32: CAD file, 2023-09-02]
SolidWorks Design/Assemear.SLDASM
earpart
Max4466

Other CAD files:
SolidWorks Design/Assemlowerand batterycover.SLDPRT
SolidWorks Design/PCB1.SLDASM
SolidWorks Design/PCB3.SLDASM
